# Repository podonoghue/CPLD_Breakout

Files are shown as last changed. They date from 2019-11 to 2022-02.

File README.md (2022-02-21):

# CPLD_Breakout
Break-out board for XC2C64A-7VQG44C CPLD

Features:  
* Alternative JTAG connectors (Xilinx 2x7 boxed header or simple 6-pin header)
* Simple header is right-angled so is keyed by proximity to the board 
* Reverse supply protection by Schottky diode (assumes current limited supply!)
* Device programming pins are clamped to the __Gnd__/__Vdd__ to reduce damage from static or incorrect JTAG connector.
* Reset switch
* User LED
* Power indication LED
* Board pin spacing is suitable for bread-board (but __not__ DIL socket)
* 1.8V voltage regulator for CPLD
* Fixed 3.3V I/O
* All pins are numbered or labeled

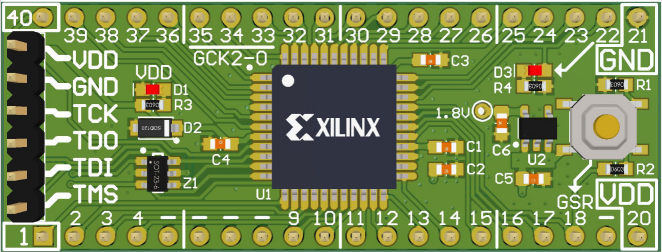
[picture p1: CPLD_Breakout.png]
An image Board Image


[Documentation](https://raw.githubusercontent.com/podonoghue/CPLD_Breakout/master/CPLD_Breakout.pdf)

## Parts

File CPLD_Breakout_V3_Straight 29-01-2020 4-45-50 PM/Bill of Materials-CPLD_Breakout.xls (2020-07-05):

Comment | Description | Designator | Footprint | LibRef | Quantity | Farnell PN | Digikey | LCSC
B5819W | Schottky diode1A 40V Vrm SOD-123 | D2 | SOD-123 | B5819W | 1 |  |  | C8598
2.2uF | Capacitor | C5, C6 | CCNP1608-0603 | Cap | 2 |  |  | C23630
100nF | Capacitor non-polar SMT 0603 | C1, C2, C3, C4 | CCNP1608-0603 | Cap_CCNP_0603 | 4 |  |  | C14663
CM1293A-04SO | Ultra low capacitance quadruple rail-to-rail ESD protection | Z1 | SOT457_N | CM1293A-04SO | 1 | 2533258 | CM1293A-04SOOSCT-ND | C393377
Header, 6-Pin | Header, 6-Pin | P3 | HDR1X6S | Header 1x6 | 1 | 1835481 | 609-3272-ND
Header, 10-Pin | Header, 10-Pin | P1, P2, P4, P5 | HDR1X10S | Header 1x10 | 4
LED Red | LED 0603 Red | D1, D3 | LED1608-0603-RED | LED-0603-Red | 2 | 1581239 |  | C2286
1K | Resistor SMT 0603 | R3, R4 | CR1608-0603 | Res_CR0603 | 2 |  |  | C21190
10K | Resistor SMT 0603 | R1, R2 | CR1608-0603 | Res_CR0603 | 2 |  |  | C25804
RT9198-18GBR | 1.8V 300mA LDO with enable, uses low ESR cap (ceramic) | U2 | SOT23-5 | RT9198-18GBR | 1 | 2363142 | RT9198-18GBR-ND | C130834
SMD-SW-4_5.1x5.1x2.0_M | Tactile Switch SPST 5.10mm X 5.10mm (1.5mm=C318884) (2.0mm=C318888) (3.5mm=C318886) | RESET_BTN | SMD-SW-4_5.1x5.1x2.0_M | SW_PB-TS | 1 |  |  | C318888
XC2C64A-7VQG44C | CoolRunner-II 1.8V, 64 Macrocell CPLD, 33 User I/Os, 44-Pin VQFP, Commercial Grade, Pb-Free | U1 | VQG44_M | XC2C64-7VQ44C | 1 | 2831286 | 122-1410-ND
XilinxJTAG |  | P6 | HEADER_2x7_2mm | XilinxJTAG | 1

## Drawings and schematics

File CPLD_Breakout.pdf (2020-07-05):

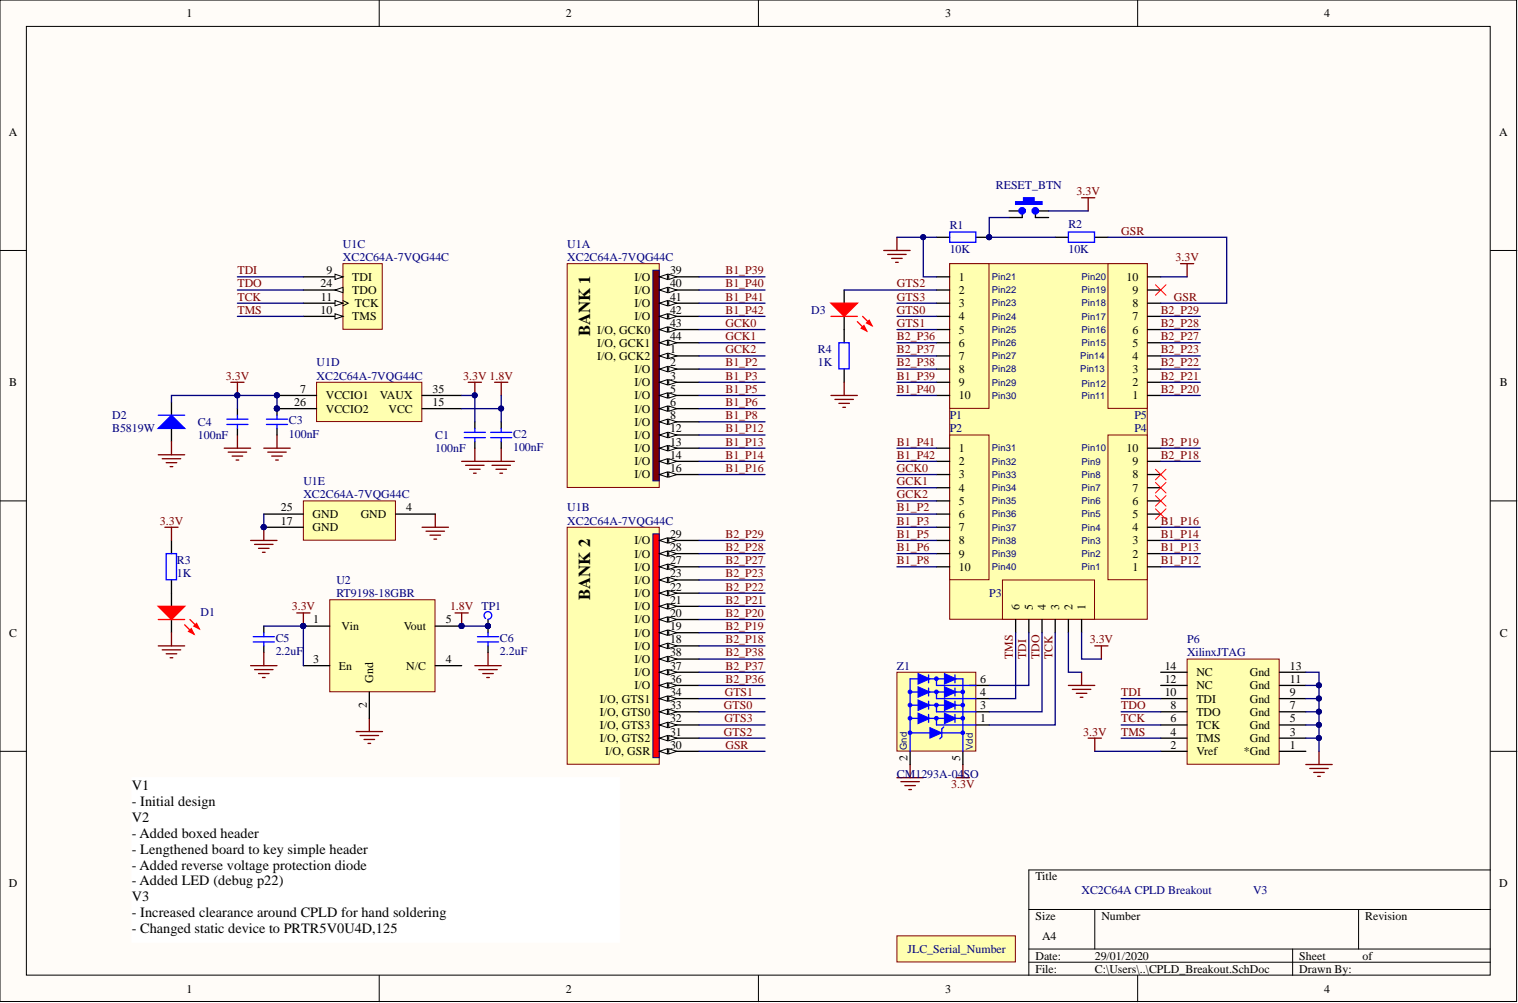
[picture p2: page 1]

- Initial design
- Added boxed header
- Lengthened board to key simple header
- Added reverse voltage protection diode
- Added LED (debug p22)
- Increased clearance around CPLD for hand soldering
- Changed static device to PRTR5V0U4D,125

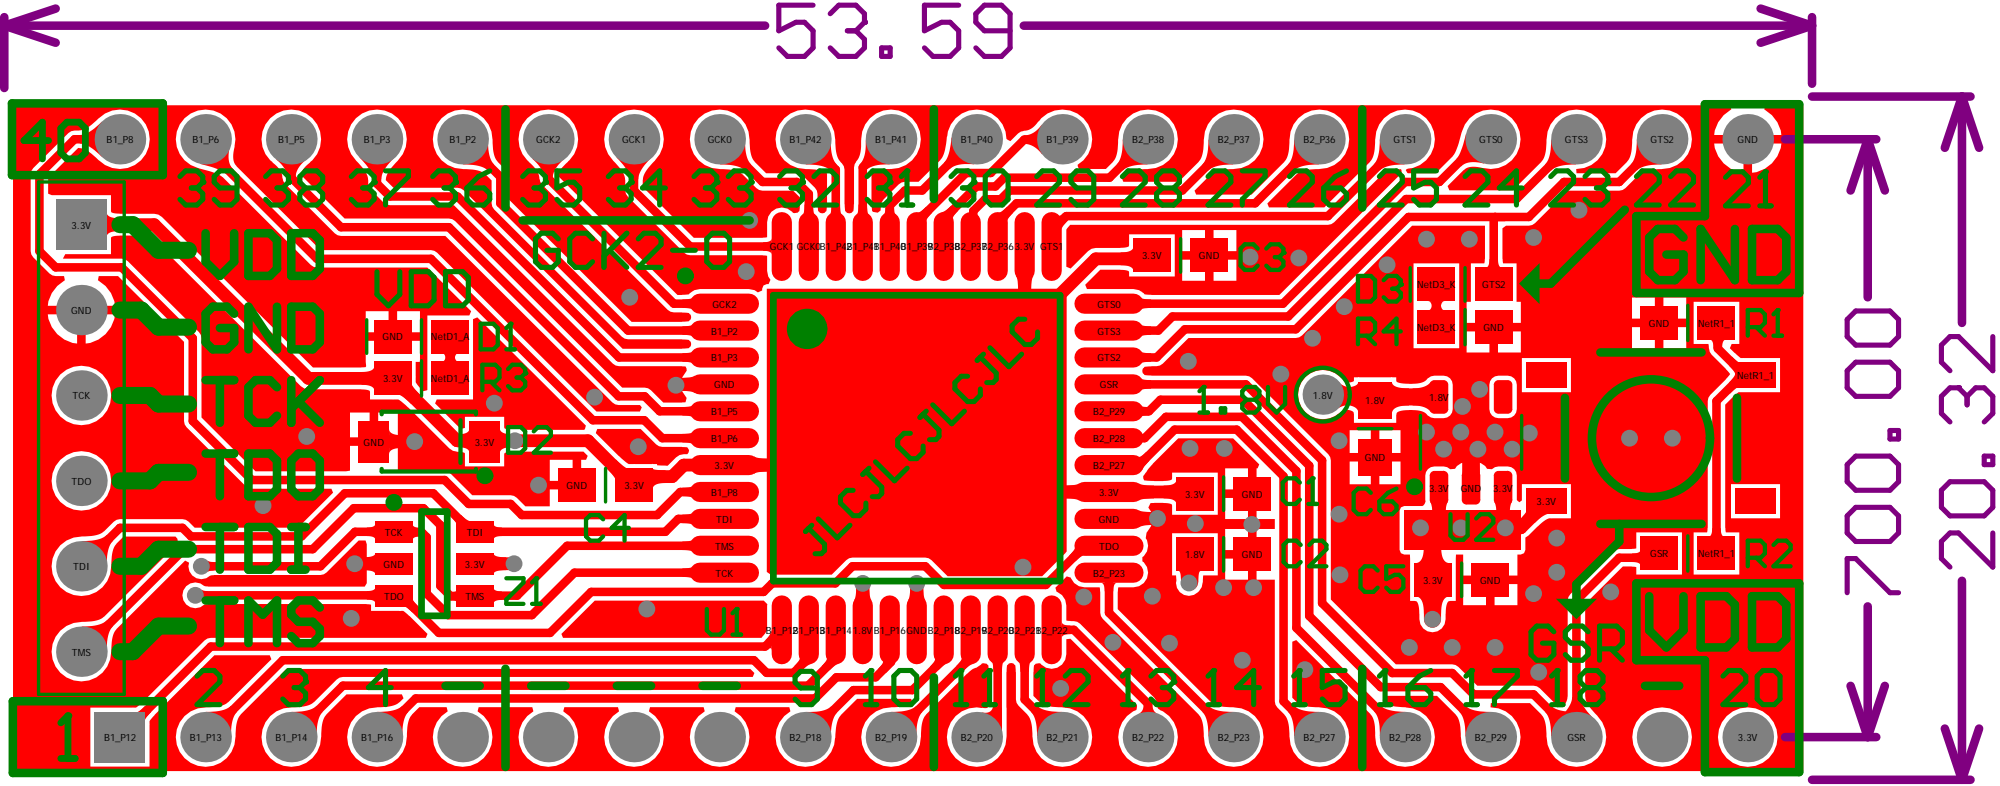
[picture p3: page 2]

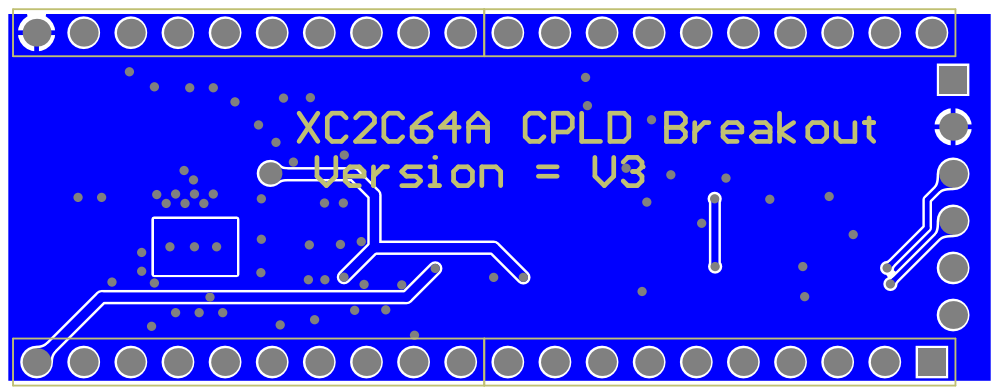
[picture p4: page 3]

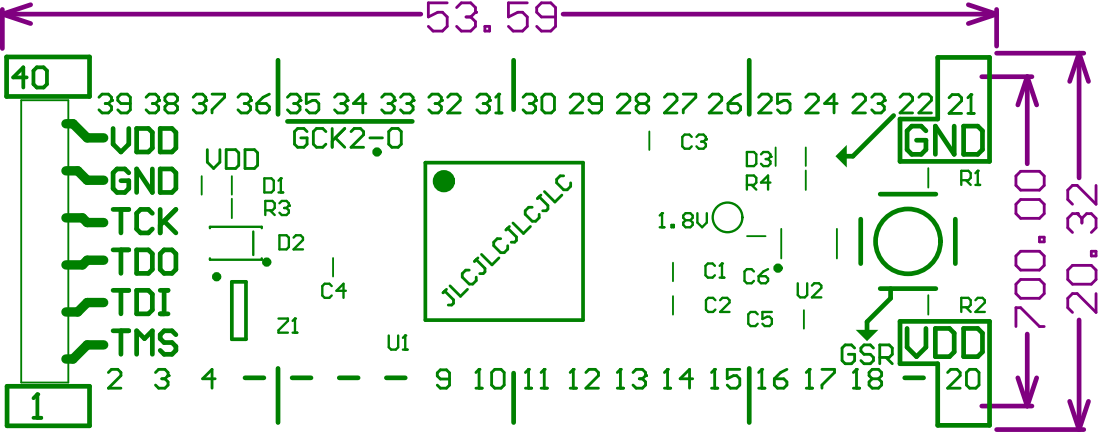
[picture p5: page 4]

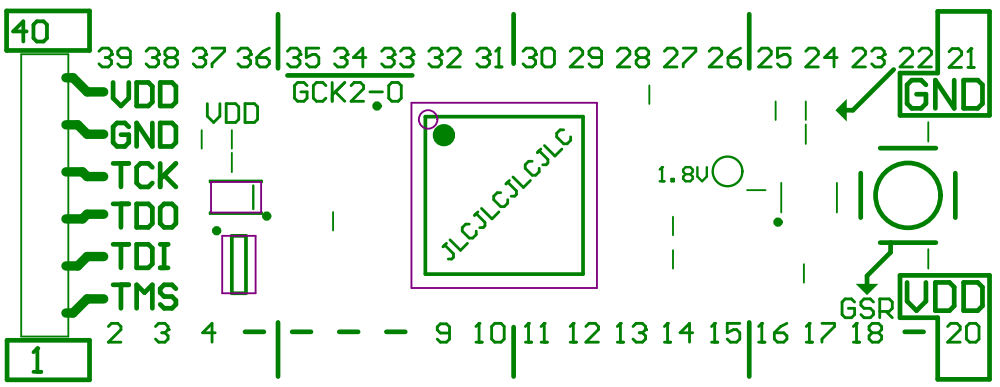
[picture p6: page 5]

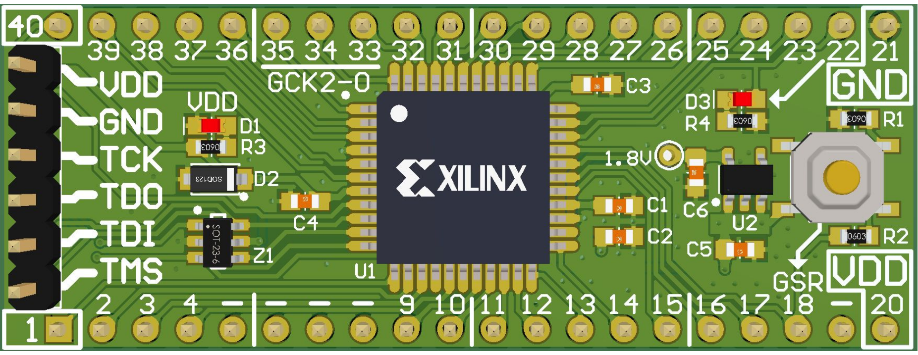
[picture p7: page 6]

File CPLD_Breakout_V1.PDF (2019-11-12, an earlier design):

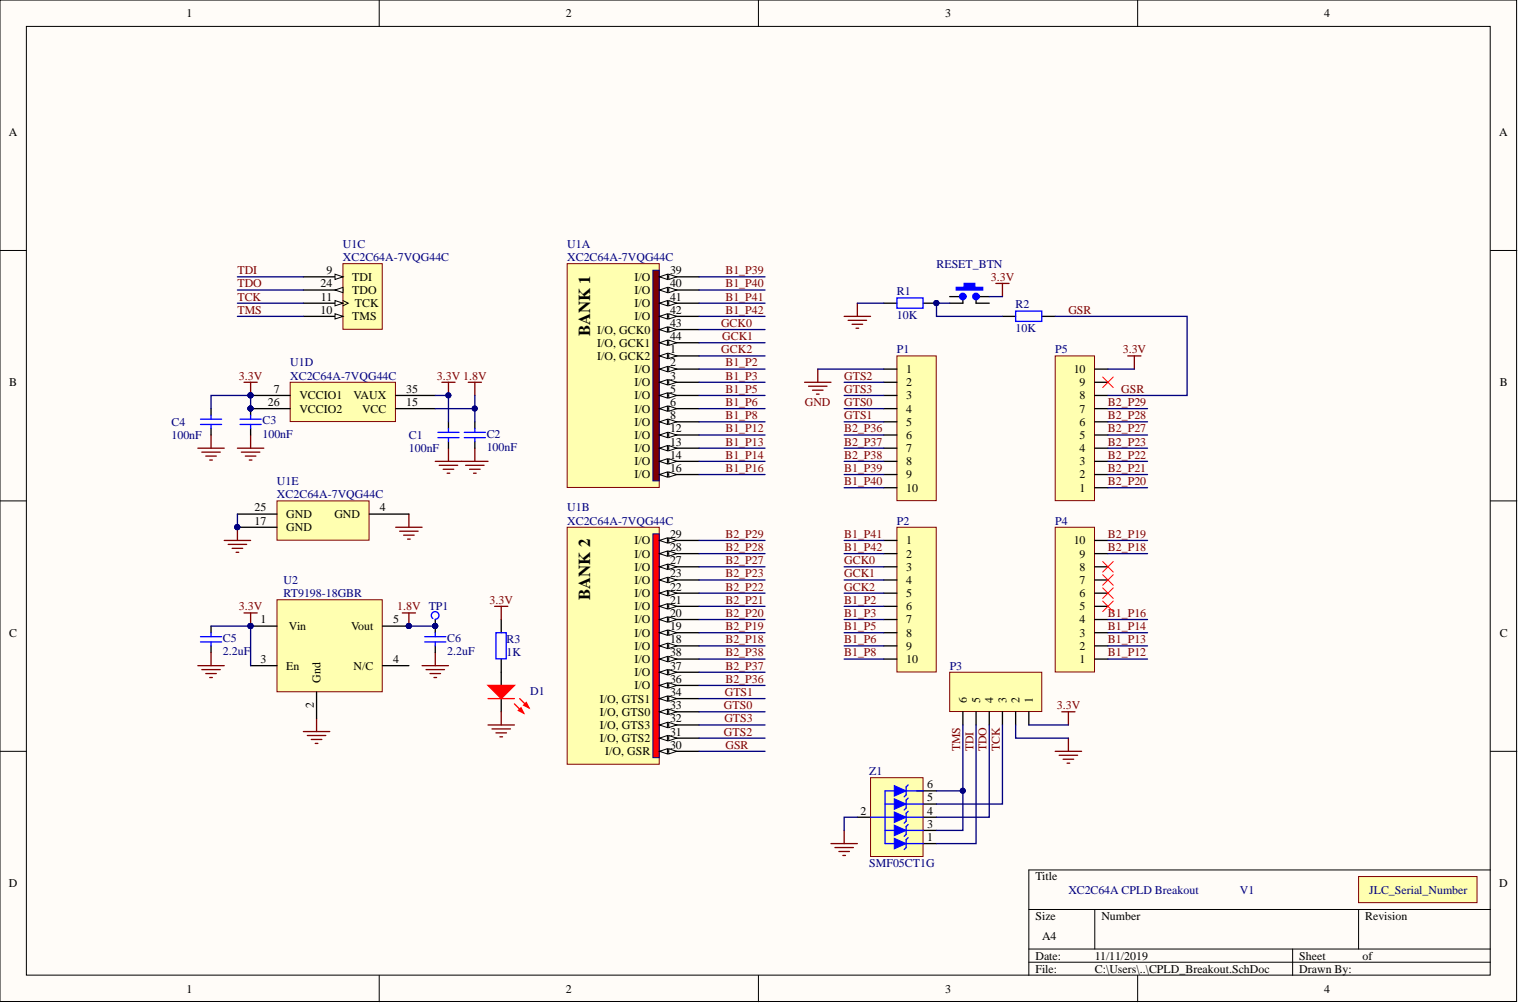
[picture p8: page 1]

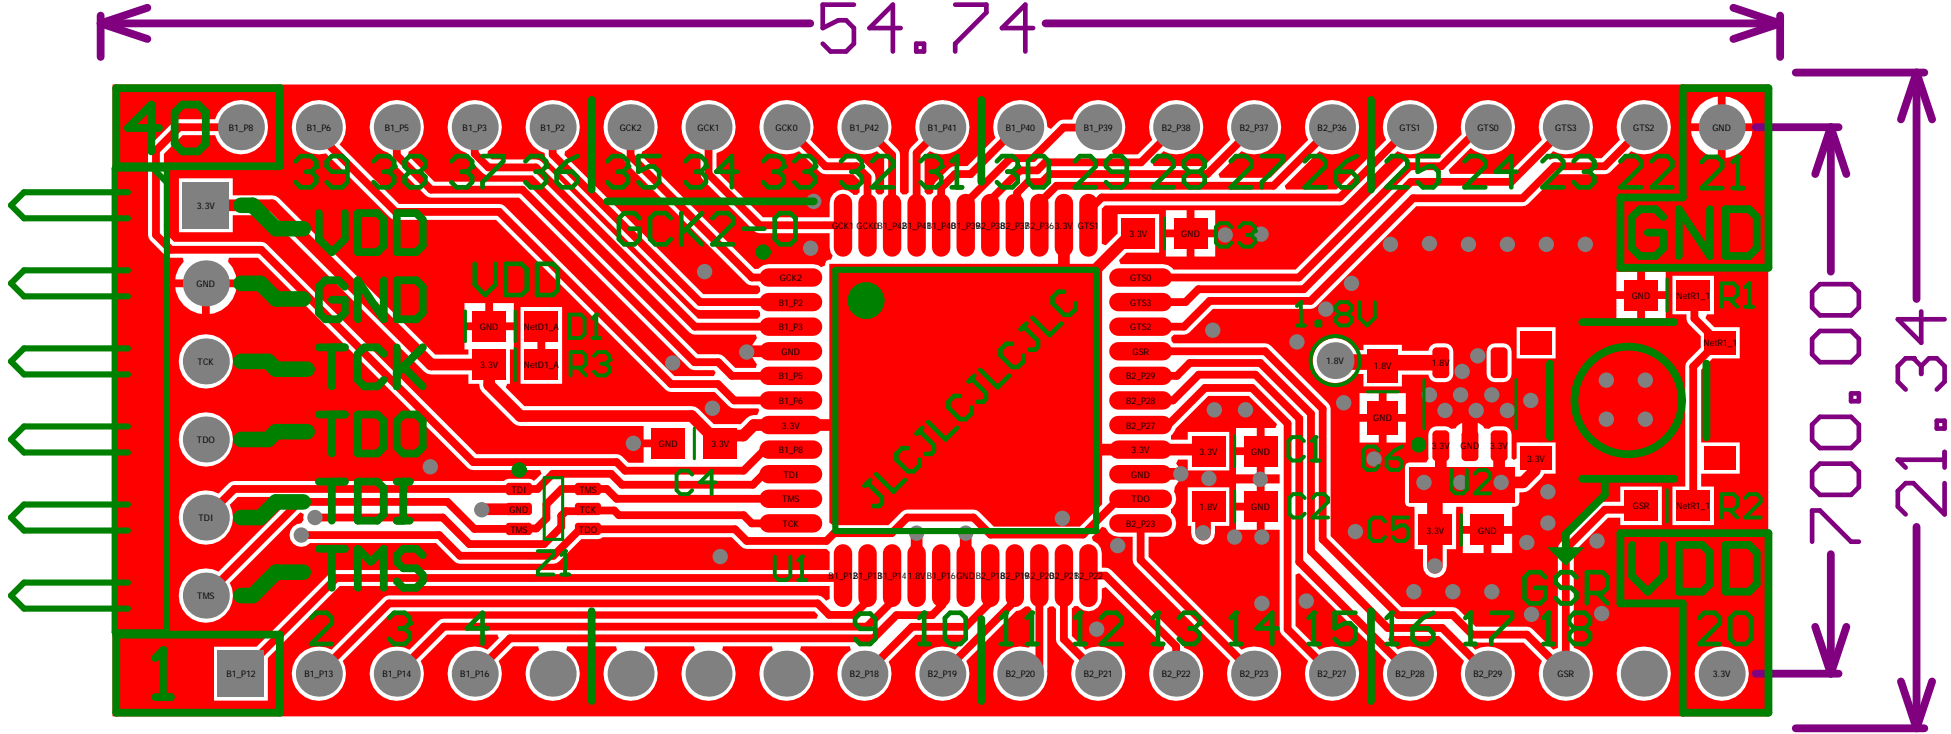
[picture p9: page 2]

GND | B2_P27

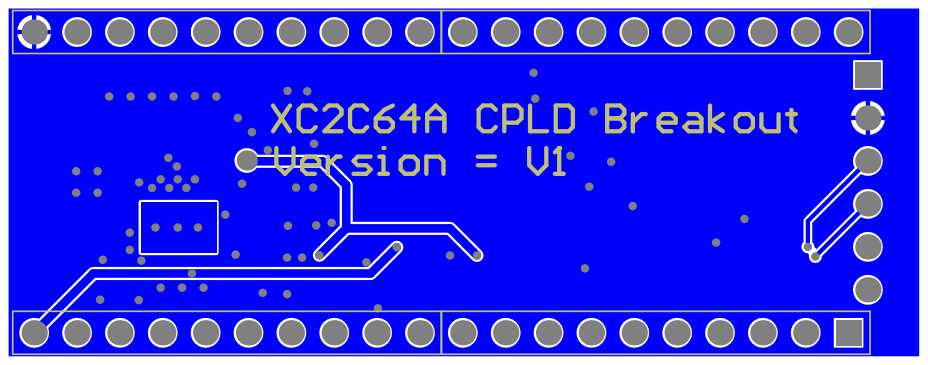
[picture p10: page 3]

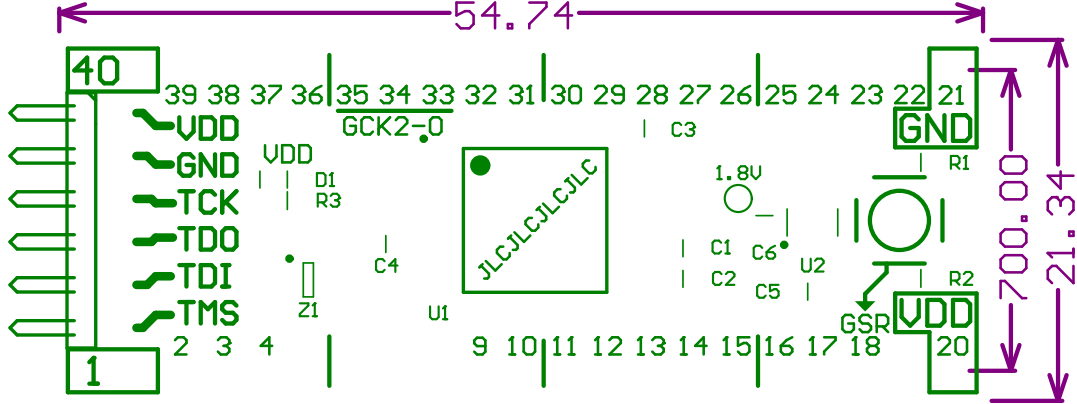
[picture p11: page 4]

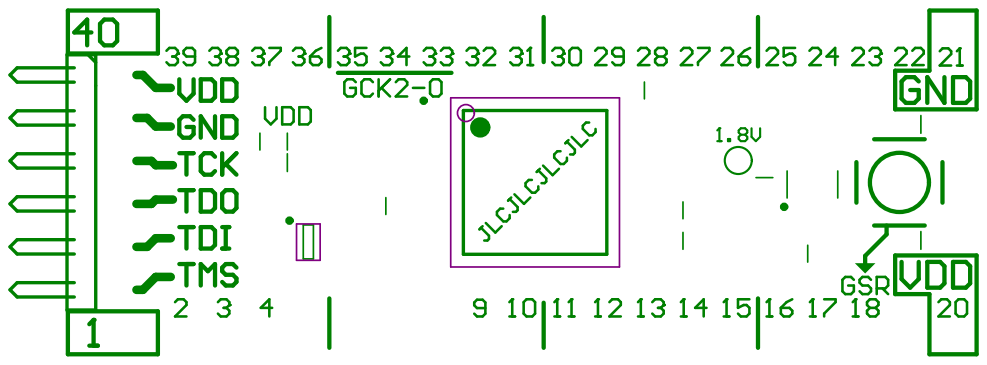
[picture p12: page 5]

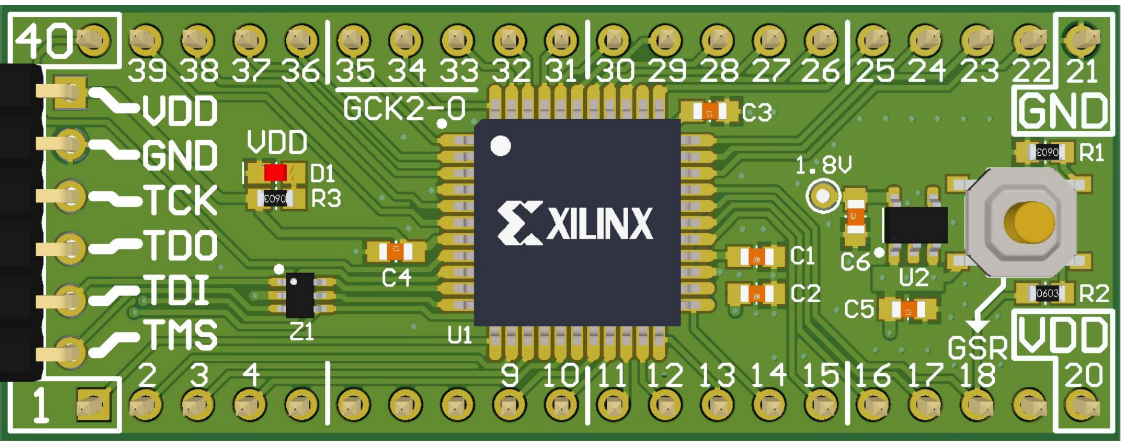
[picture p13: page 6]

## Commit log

2019-11-10 Ready for first spin
    [Bill of Materials-CPLD_Breakout.xls, CPLD_Breakout.GBL, CPLD_Breakout.GBO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]
2019-11-11 Added JLC PCB serial number location
    [Bill of Materials-CPLD_Breakout.xls, CPLD_Breakout.GBL, CPLD_Breakout.GBS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]
2019-11-12 Initial Manufacture using JLCPCB
    [Bill of Materials-CPLD_Breakout.xls, CPLD_Breakout.GBL, CPLD_Breakout.GBS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]
2019-11-16 Added reverse voltage protection diode.
    [CPLD_Breakout.PcbDoc, CPLD_Breakout.PrjPcb, CPLD_Breakout.SchDoc]
2019-11-18 Post prototype manufacture testing. Minor tweaks.
    [CPLD_Breakout.PcbDoc]
2019-11-28 Added alternative connector (also serves to polarise simple connector)
    [Bill of Materials-CPLD_Breakout.xls, CPLD_Breakout.GBL, CPLD_Breakout.GBO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]
2019-12-06 V2.0 - Added boxed header - Lengthened board to key simple header - Added reverse voltage protection diode - Added LED (debug p22)
    [Bill of Materials-CPLD_Breakout(Simple JTAG header).xls, Bill of Materials-CPLD_Breakout.xls, CPLD_Breakout.GBL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]
2019-12-17 V2.2 Minor tweaks
    [CPLD_Breakout.PcbDoc, CPLD_Breakout.PrjPcb, CPLD_Breakout.SchDoc]
2019-12-17 V3 Minor tweaks
    [Bill of Materials-CPLD_Breakout(Simple JTAG header).xls, CPLD_Breakout.GBL, CPLD_Breakout.GBO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]
2020-01-02 V3 Manufacture
    [Bill of Materials-CPLD_Breakout.xls, CPLD_Breakout.GBL, CPLD_Breakout.GBO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]
2020-07-05 Misc Sync
    [Bill of Materials-CPLD_Breakout.xls, CPLD_Breakout.GTL, CPLD_Breakout.Pcb_Straight.GBL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]
2022-02-20 Added Board IMage
2022-02-20 Fixed Board Image
